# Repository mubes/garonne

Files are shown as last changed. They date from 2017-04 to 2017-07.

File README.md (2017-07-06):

```
                                       ++++++++++++++++++  
                                  +++++++++++++++++++++++++++++   
                              +++++++                      +++++++++  
                          +++++++                               +++++++++++++   
         ++++++++++++++++++++                                         ++++++++++   
    +++++++++++++++++++++                                                     +++  
   +++++                                                                       +++  
  +++         ######### ######### ########  #########  #########   +++++++      ++  
  +++  +++++ ####  #### ######## ####  #### ##### #### #### ####  +++  ++++    +++  
  +++   ++++ ###     ## ###      ###    ### ###    ### ###    ### ++++++++   +++  
   ++++ ++++ ########## ###      ########## ###    ### ###    ### ++++    +++++  
    +++++++   ###### ## ###       ########  ###     ## ##     ###  ++++++++++  
```

Introduction
============
The Garonne project is a simple infrastructure for autonomous and ADAS model vehicles. It
has been run on numerous embedded and application platforms. The system consists of 
a Low Level Board (LLB) which is a real time embedded plaform (optionally multi-core)
and a High Level Board (HLB) which performs the 'reasoning' behind the actions the 
system takes.  Many different platforms have been used for the HLB and the LLB including
Tegra TK1 and full blown PCs. 

Its designed to be cheap to build, modify and crash....but to be a reasonably powerful
and extensible platform at the same time.

In the current implementation, for ease of access, the High Level Board is minimally a 
Raspberry Pi and the Low Level Board is a NXP LPCXpresso LPC4367 204MHz CORTEX-M4 + 2x
CORTEX M0 which provides a significant amount of real time computing power. The HLB
runs Linux, programmed in Python, and the LLB is based on FreeRTOS and is programmed
in C. The Commander (that animates the system and provides objectives to be reached) can
run on pretty much anything, but the simple code provided will work perfectly well on a
second RaspberryPi....you can even use Force Feedback wheels etc. for 'driving' the vehicle remotely.

The project was orignally created by Technolution BV. It was first demonstrated at the 
ITS World Congress in Bordeaux in 2016 (Hence, the codename 'Garonne', the river that 
Bordeaux lies on) based on bespoke hardware. It has been ported to COTS hardware by
Technolution and is now released for open use.

Getting Started
===============
Generally speaking, a Garonne system will consist of at least one vehicle, a control platform
(consisting of a Low Level Board (LLB) and a High Level Board (HLB) and a command platform,
which is generally remote. All of this runs on a physical vehicle which ends up
looking something like this;

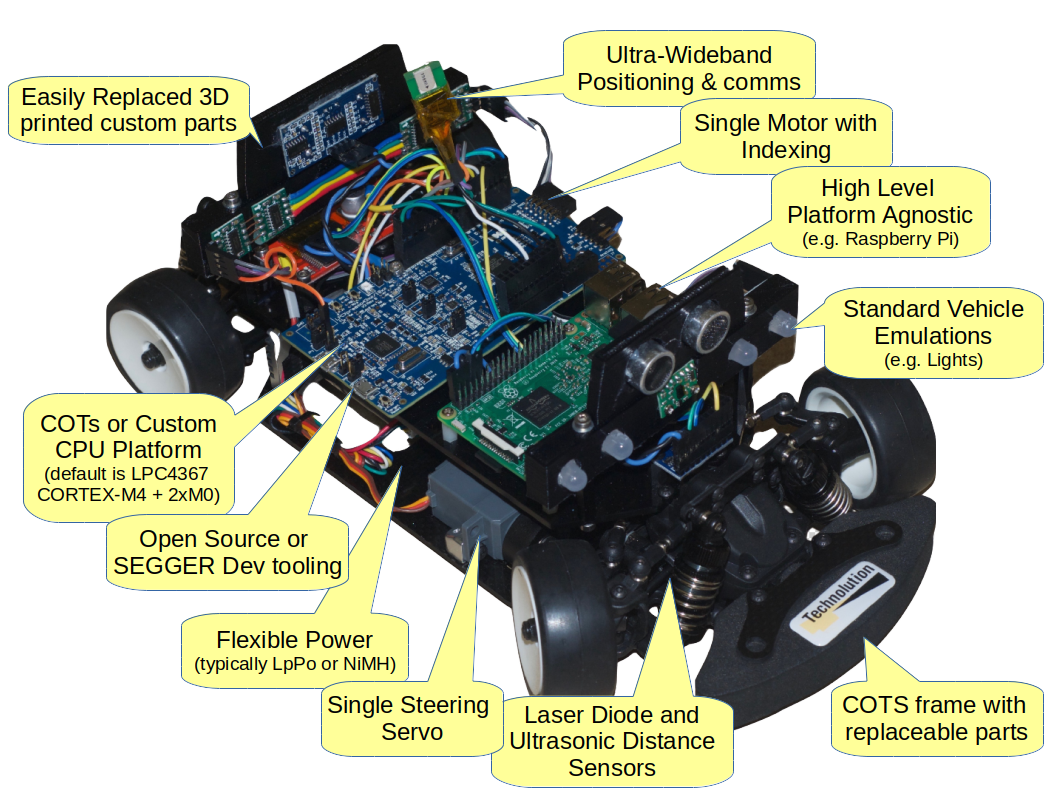
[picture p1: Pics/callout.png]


...so, let's get started;

Physical Vehicle
----------------
Generally speaking, you can use most remote controlled cars for the physical vehicle, the requirements
are not very onerous. 

The shopping list looks like the following (Full list of compnents and quantities is at the foot of this note);

* ***M.Rage chassis, assembled***.  [Hobbyking](https://hobbyking.com/en_us/bsr-racing-m-rage-1-10-4wd-m-chassis-un-assembled-kit.html). The assembled bit is an exercise for the reader.

* ***Steering Servo***...just a bog standard analogue servo will be fine. Something like [this](https://hobbyking.com/en_us/turnigytm-tgy-9025mg-mg-servo-1-8kg-0-09sec-11g.html).

* ***Pololu motor***, mounted in chassis, with drive pinion. We use the 4.4:1 variant which is expensive, but comes with itw own encoder and they're available from distributors around the world. [Pololu item number 2270] (https://www.pololu.com/product/2270).

* ***Drive Pinion***. The most specific bit of the whole setup. These are 31 tooth 48P pinions with 5mm bore. We get ours from neil at rwracing.co.uk. Take a guess at his email address.

* ***Power Switch***. You can use anything for this really, but the plastics have a 13x19.5 hole cut to take a snap-in switch. The ones we have are marked KCD1-104 and work fine. Available for cheap from the usual outlets.

* ***Mounting plastic for the electronics***. No way out of this one, you've got to make them, or talk very nicely to me to see if we've got any spare, we often have, but shipping outside of local territory tends to end up more expensive than making new ones.  The drawings to make them from are in the git repository, and [Elecrow] (https://www.elecrow.com/) will make you more than you'll ever need in 3mm acrylic for very cheap.

* ***LPC4367 LPCXpresso board***. These are available from [Farnell] (http://uk.farnell.com/nxp/om13088/dev-board-32bit-dual-core-mcu/dp/2519578) and elsewhere.  Again, not cheap, but you're getting a CORTEX-M4 and two CORTEX-M0 CPUs here, complete with development environment and debugger.

* ***MPU9250 9D sensor board***. Search for '9DOF MPU9250' or similar on eBay. It's just a chip on a board so it's difficult for them to screw it up too badly. Make sure you end up with a 9250 board and not a 65 series board though....they're largely identical but the one with MPU65 written on the top doesn't have the magnetometer built in.

* ***Raspberry Pi 3***...'nuff said. The plastics also support the little mini ones, and the PiW has wifi on now too. Which one you choose is dependent on how much processing you want to do on the vehicle. We've used all sorts for this job from a Pi to a TEGRA K1 and a Parallella. You can connect to the LLB via TTL-serial or USB, so there's flexibility here.

* ***VHN2SP30 motor driver***. Again, this is an eBay job.  You only need the single one, not the dual that is set up as an Arduino shield.

* ***5V power supply***. There are 1001 of these. We use the little MP1584 modules set to 5V with a dab of nail varnish on the pot afterwards. Use whatever you prefer but *beware* there are many stories of fake modules coming out of China. They usually work fine but I wouldn't trust them anywhere near their stated current limits!

In addition to this lot you will need some male to female and female to female 10cm and 20cm Dupont 
jumpers, and some nylon m3 standoff pillars. In the Wiring directory you will find a set of wiring digrams for Power;

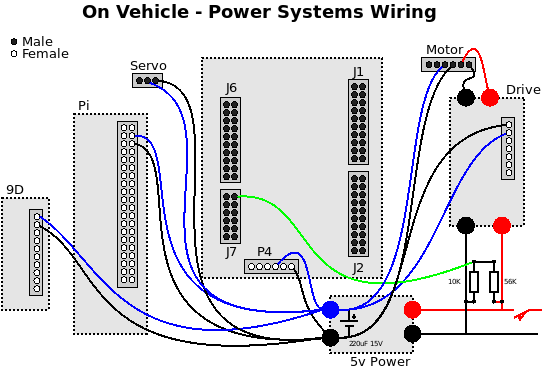
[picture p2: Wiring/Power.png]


... and for signalling;

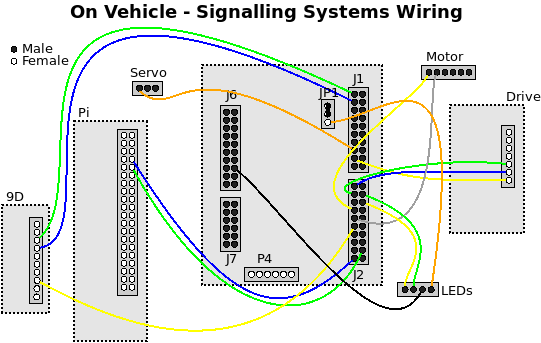
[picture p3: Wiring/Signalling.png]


Higher resolution versions of these diagrams can be found in the `Wiring` directory in PDF format.

Low Level Board
---------------
Bringing up the Low Level Board (LLB) requires the use of the GNU ARM gcc compiler suite. You can download that directly from [ARM] (https://developer.arm.com/open-source/gnu-toolchain/gnu-rm) and then use something like GNU ARM Eclipse to fold it into an IDE (http://gnuarmeclipse.github.io/) or, the easier option, is to head over to NXP and download either LPCXpresso or MPUXpresso from their site. MCUXpresso is the more recent suite, and is arguably more powerful, but it's a new product and at the time of writing we found LPCXpresso 8.2.2 to be more solid than MCUXpresso 10.0.0....but the letter is likely to be updated frequently, so YMMV.  Having said that, as we've brought up the M0 cores, we've not found either of these suites to be great, so we've installed the Segger JLink firmware (available for download from the [Segger Site](https://www.segger.com/jlink-lpcxpresso-ob.html) ) and used it with the [GNU Arm Eclipse](http://gnuarmeclipse.github.io/) setup. This makes for quite an impressively capable setup.

The code for the LLB is well commented and will build directly from the Makefile with a `make` command...or import it as a makefile project into one of the aforementioned environments.  It will flash directly onto the LLB using the built in debugger. You've got to go a _long_ way out of your way to brick this setup...indeed, I doubt you could do it without deliberately setting out to do so.

Structure of the LLB Code
-------------------------

The LLB code is reasonably well structured, and there are lots of optional components that can be included via conditionals in the makefile (e.g. for networking, SD cards and CAN interfaces).  The primary components to be interested in are;

* `config.h` : The main configuation file, which pulls in a susbsidiary configuration file `config-lpc4367.h` or `config-lpc4370.h` which are the only two we have released. In each of these files you will find things like pin allocations for the various components and the configuration of I/O flows (e.g. which UART is used for the UI and which is used for HLB communication, for example). In general make changes in these files rather than the program files themselves where possible.

The code for the various CPUs lives in subdirectories. For now we only concern ourselves with the m4 code, which we split into several groups;

----
**Program Flow Control**

* `main.c`: Sets up the system, calls essential configuration routines, and then gets out of the way having gotten everthing going.  The main thread of execution is maintained in...

* `mainloop.c`: Runs two threads. One for the i2c tasks, and one for the primary tasks.  These are seperated to avoid timing dependencies between the two. After initialisation the two threads in `mainloop:_mainThread` and `mainloop:i2cThread` represent the backbone of execution for the system.

* `ui.c`: The management and reporting UI. Not generally used in active operation, but very useful for debug and proving.

----
**Offboard Communications**

* `serport.c`: Abstracted interface to all of the serial ports, both 'real' TTL ones and 'virtual' USB ones.

* `lmsMsg.c`, `lms_rx.c` & `lms.c`: The interface to/from the HLB. All messages are encoded and decoded here before being dispatched to the right places.

* `uartHandler.c`: Looks after the 'real' UARTs.

----
**I/O**
 
* `gio.c`: The generic I/O module. Looks after the flashing lights, ADC and other low level stuff that is not worthy of its own module.

* `leds.c`: Code for driving LED strings (for indicators and headlights etc.).

----
**Device Drivers and Real World Interfaces**

* `rotenc.c`: Provides a clever little routine to maintain the rotary encoder count from the motor.

* `dist.c`: Distance measuring via whatever transducers are in use.

* `vldist.c`: Distance module when using the ST VL transducer.

* `motor.c`: Motor (actuator) driving for both the direct drive motor and the Servo.

* `can.c`: Is a prototypical CAN interface. It was used for hardware proving and is not active in current builts.

* `audio.c` : Is a simple DMA based audio handler. Not wired in one the current board, but can trivially be added. The samples it plays out are stored in `speedy.c`.

* `sdif.c`: Is the iterface to the SD Card that can be used for recording logging data etc. This was used in hardware proving and is not active in current builds.

* `nined.c`: Simple i2c interface to the 9D sensor. 

* `i2chandler.c`: Generic i2c handler.

* `usb/`: Files relating to the USB interface. Most of the interface is implemented by ROMmed routines, but this code provides the interface to those.

* `enet/`: Files relating to the Ethernet interface.  This is not active/needed at the moment (these files were used for hardware proving) but it's trivial to add by just provisioning a connector onto J6 of the LLB....previous versions of Garonne have used Ethernet for the interface between the LLB and the HLB

----
**System Management**

* `fault_handler.c`: Provides support for debugging the bane of every ARM programmers life, HardFaults.

* `config.c`: Configuation support and Non-volatile storage. Asserts and debug printing are also handled in here.

* `stats.c`: Simple stats management package for FreeRTOS....it's really useful to know just how busy the CPU is!
                                                               
* `llb_init.c` & `startup_lpc43xx.c`: Deal with the booting of the system.

There is code that runs on the M0 board for interfacing to the Ultrawideband radio and a Quaterion structure for the 9D sensor. I'm afraid we can't make the source code for these files openly availble but you're free to use the code with the Garonne platform (See the licence in the `bindist` directory, where the binary blob also lives).  If you _do_ need access to the source for this module then drop us a note and we will sort something out...but we've got to eat too!

High Level Board
----------------
The high level board is reponsible for the 'reasoning' that the on-board systems have to perform. It's also responsible for the interface to the outside world (over WiFi, in the implementation that is released). It's based on a RaspberryPi and a Pi3 or ZeroW both offer the WiFi on board.

The image on the board is based on Rasbian (downloadable from the Pi Foundation), then install Python3, the PySerial and evdev extensions, and you're ready to run the `vehicleserver` which is in the `python` directory of the distribution. You can edit the file `/etc/rc.local` and add the following lines to get the system to auto-start;

```
/sbin/iwconfig wlan0 power off
/home/icarus/runvs >> /home/icarus/vehicleserver.log 2>&1 &
```

If you _do_ decide to to start `vehicleserver` from the command line then the `-v` option will provide you with some information as to what it is doing.  In general, the vehicleserver won't do anything except the status quo until it receives a command from the outside world, which brings us to the highest level of the system;

Commander
---------

The commander is the part of the system that tells the vehicle(s) what to do. In the released implementation you will find a `wheelclient` in the `python` directory of the distribution. This allows a number of different controllers to be used to control the vehicle directly. Currently supported controllers are;

* Logitech G29 Driving Force Racing Wheel (uses the force feedback - currently the best choice)
* Generic Steering Wheel Controller
* PLAYSTATION(R)3 Controller over Bluetooth
* Goodbetterbest Ltd Gioteck VX2 Wired Controller
* Microsoft X-Box 360 pad

When multiple controllers are connected to the Commander the selection amongst them will be performed in the order listed above.  Adding new controllers is trivial via the code in `wheelclient`.

`wheelclient` will run on any Linux-style platform. For convinience it is often run on a second RasberryPi...indeed, if you're using a Bluetooth controller, it can even be run on the HLB.

`wheelclient` needs to be told where to 'find' the HLB on the network. A typical invocation of `wheelclient` would therefore be;

```
wheelclient -s icarus32n4.local
```

Parts List
----------

| Component | Per Vehicle |
| ---|:---:|
| Frame		 | 1 |
| Plastic Motor Mount	 | 1 |
| Polulu 2270 motor	 | 1 |
| Servo Motor | 1 |
| 31 tooth 48P pinion with 5mm bore	 | 1 |
| Acrylic Baseplate | 1 |
| 10mm M2.5 Nylon Spacer 	 | 4 | 
| 10mm M3 Nylon Spacer	 | 9 |
| m3 nut	 | 9 |
| 30mm Nylon Hex Standoff	 | 4 |
| 6mm M3 Hex Head bolt	 | 13|
| M3 Washer | 4 |
| 8mm M2.5 Cross Head Screw	 | 4 |
| 10x1 Dupont Housing | 1 |
| 10x2 Dupont Housing | 3 |
| 7x1 Dupont Housing | 1 |
| 6x2 Dupont Housing | 1 |
| 6x1 Dupont Housing | 1 |
| 20x2 Dupont Housing | 1 |
| 10cm 40 way Male to Female Dupont Jumper | 1 |
| 20cm 40 way Male to Female Dupont Jumper	 | 1 |
| 15cm 40 way Male to Female Dupont Jumper	 | 1 |
| Hookup wire for Battery (Black & Red)		 | 1 |
| Hookup wire for 5V Distribution (Black & Blue) | 1 |
| 56K 1/4 Watt Resistor	 | 1 |
| 10K 1/4 Watt Resistor	 | 1 |
| MPU9250 9D Sensor Board	 | 1 |
| Raspberry Pi 3 or PiW	 | 1 |
| 8GB uSD Card | 1 |
| Ultrasonic Transducer	 | 2 |
| LPC4367 LPCXpresso board	 | 1 | 
| VHN2SP30 Motor Driver Board	 | 1 |
| MP1584 PSU (Adjust to 5V)	 | 1 |
| KCD1-104 Power Switch | 1 |
| DWM1000 Module | 1 |

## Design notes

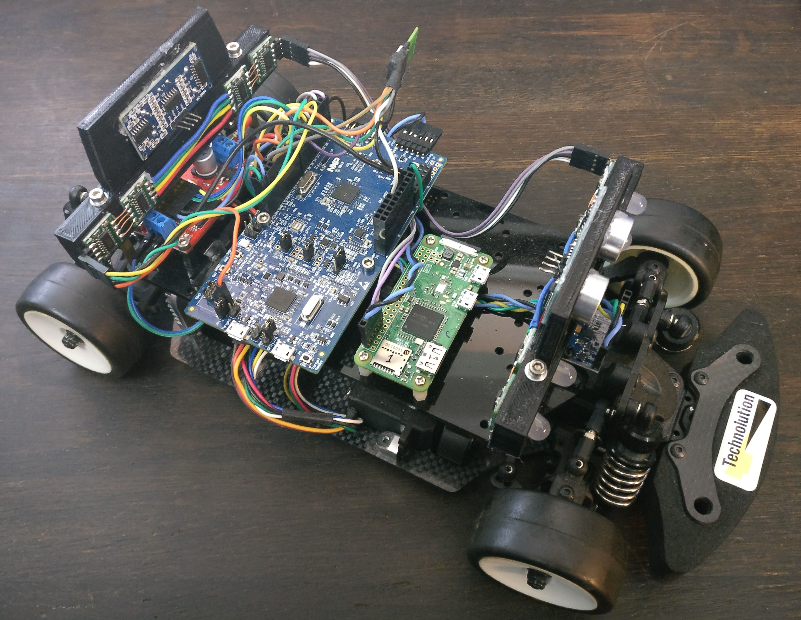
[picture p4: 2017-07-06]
Pics/Vehicle.jpg

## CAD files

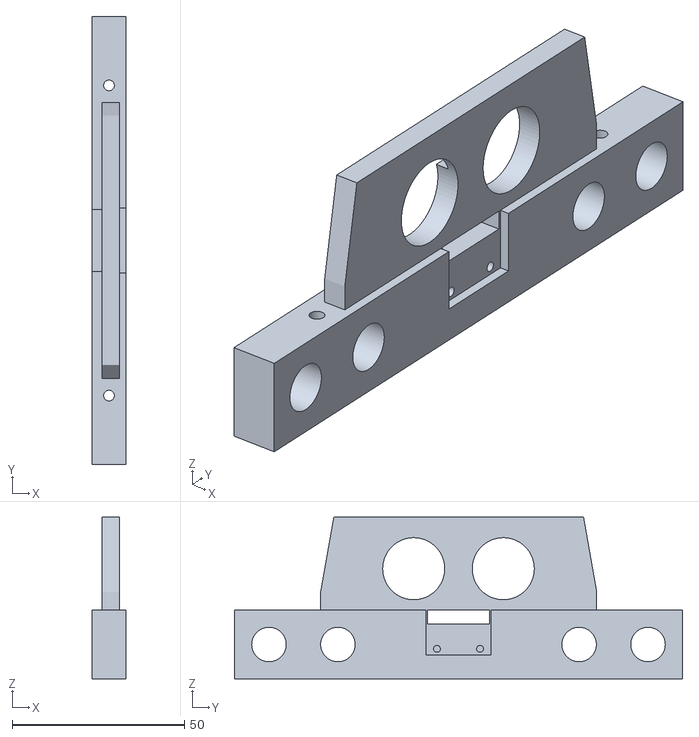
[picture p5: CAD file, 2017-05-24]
prints/bakcrossbar.stl
10.0 x 130.0 x 47.0

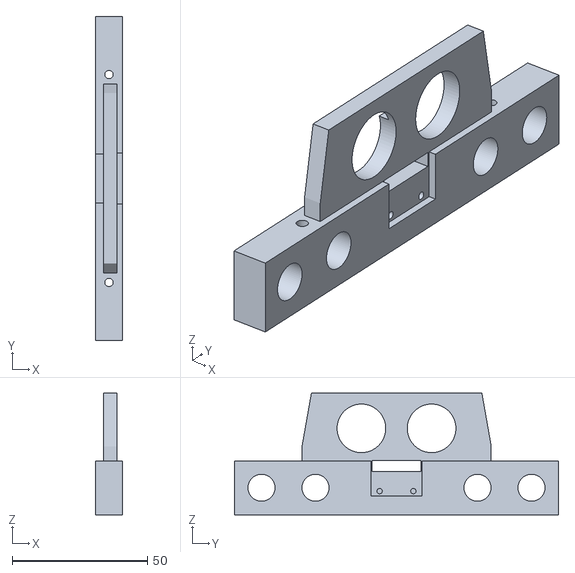
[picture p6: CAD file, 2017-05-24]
prints/frontcrossbar.stl
10.0 x 120.0 x 45.0

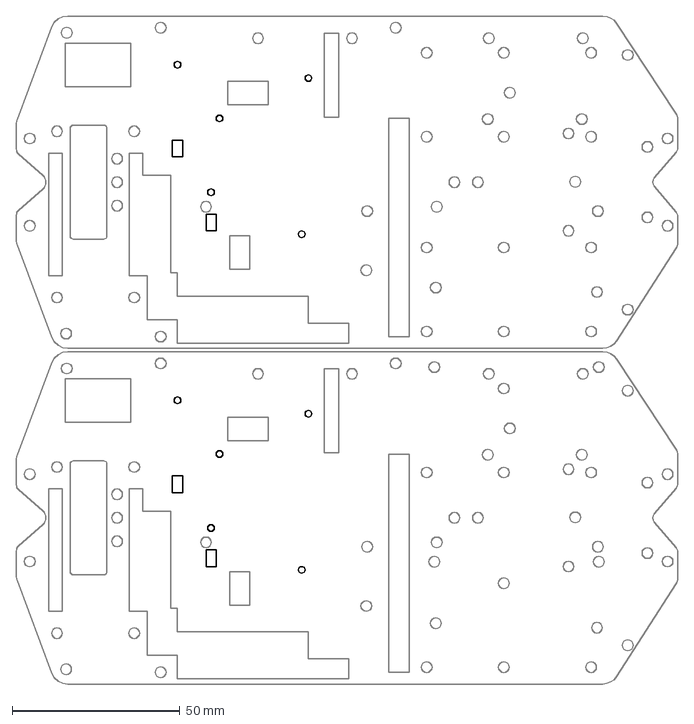
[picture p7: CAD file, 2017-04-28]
prints/top-v4.dxf
197.0 x 199.0 mm

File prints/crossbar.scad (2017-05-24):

$fn=64;
rlength=100;
length=120;
backlength=130;
width=10;
height=20;

frontcutdepth=2;
frontwidth=19;
frontDepth=13;
hcentres=12.5;
hdep=7.25;

topcutdepth=4;
topcutwidth=18;

postDia=6.8;
screwDia=3.1;
postDist=77;

backpostDist=90;
rpostDist=89.5;
fixrecess=9;

radioWidth=7;
radioDepth=12;
radioLength=14;
radioHold=radioLength+12;
radioHole=4;

module front()
{
difference()
{
    // Top block
    union()
    {
        cube([width,length,height]); 
        translate([3,25,height-0.01]) cube([width-5,length-50,35]);
    }

    // Slopes for upper panel
    translate([0,17,height+6]) rotate([-10,0,0]) cube([width,8,70]);
    translate([0,length-25.01,height+6]) rotate([10,0,0]) cube([width,8,70]);

    
    // LED holes
        translate([-3,30,10]) rotate([0,90,0]) cylinder(r=5,h=15);
        translate([-1,20,10]) rotate([0,90,0]) cylinder(r=1,h=8);
        translate([-3,10,10]) rotate([0,90,0]) cylinder(r=5,h=15);
        translate([-1,length/2,10]) rotate([0,90,0]) cylinder(r=1,h=8);    
        translate([-3,length-30,10]) rotate([0,90,0]) cylinder(r=5,h=15);
        translate([-1,length-20,10]) rotate([0,90,0]) cylinder(r=1,h=8);
        translate([-3,length-10,10]) rotate([0,90,0]) cylinder(r=5,h=15);
    
    
    
    // Uptrasonic holes
   translate([0,length/2-13,height+12]) rotate([0,90,0]) cylinder(r=9,h=12);
   translate([0,length/2+13,height+12]) rotate([0,90,0]) cylinder(r=9,h=12);
    translate([1,length/2-8,height+15]) cube([5,16,8]);    
   
   // Camera
   translate([0,length/2,height+42]) rotate([0,90,0]) cylinder(r=15,h=12);    
    translate([0,length/2+13.5,height+27]) rotate([0,90,0]) cylinder(r=2,h=12);
    translate([0,length/2-13.5,height+27]) rotate([0,90,0]) cylinder(r=2,h=12);
    
    // Front cutout for laser
    translate([width-frontcutdepth+0.01,(length-frontwidth)/2,height-frontDepth]) cube([frontcutdepth,frontwidth,frontDepth+1.05]);
   
   // Holes for moutning VL laser 
    translate([width,(length-hcentres)/2,height-topcutdepth-hdep]) rotate([0,-90,0]) cylinder(r=1,h=8);
    translate([width,(length+hcentres)/2,height-topcutdepth-hdep]) rotate([0,-90,0]) cylinder(r=1,h=8);
 
        // Top recess for Dupont connector
  translate([-0.01,(length-topcutwidth)/2,height-topcutdepth]) cube([width,topcutwidth,topcutdepth+0.05]);
    
    
    // Mounting screws
    translate([width/2,(length-postDist)/2,-0.01])  
    {
        cylinder(r=postDia/2,h=fixrecess);
        cylinder(r=screwDia/2,h=height+0.05);
    }
    
    translate([width/2,length-(length-postDist)/2,-0.01])  
    {
        cylinder(r=postDia/2,h=fixrecess);
        cylinder(r=screwDia/2,h=height+0.05);
    }
    
    // Remove top when there's no camera mount needed
    translate([0,0,height+25]) cube([10,100,height+25]);
    
}    
}

module back()

{
difference()
{
    // Top block
    union()
    {
        cube([width,backlength,height]); 
        translate([3,25,height-0.01]) cube([width-5,backlength-50,27]);
    }
    
        // Slopes for upper panel
    translate([0,17,height+6]) rotate([-10,0,0]) cube([width,8,70]);
    translate([0,backlength-25.01,height+6]) rotate([10,0,0]) cube([width,8,70]);

    // Uptrasonic holes
   translate([0,backlength/2-13,height+12]) rotate([0,90,0]) cylinder(r=9,h=12);
   translate([0,backlength/2+13,height+12]) rotate([0,90,0]) cylinder(r=9,h=12);
    translate([1,backlength/2-8,height+15]) cube([5,16,8]);  

    
    // LED holes
        translate([-3,30,10]) rotate([0,90,0]) cylinder(r=5,h=15);
        translate([-1,20,10]) rotate([0,90,0]) cylinder(r=1,h=8);
        translate([-3,10,10]) rotate([0,90,0]) cylinder(r=5,h=15);
        translate([-1,backlength/2,10]) rotate([0,90,0]) cylinder(r=1,h=8);    
        translate([-3,backlength-30,10]) rotate([0,90,0]) cylinder(r=5,h=15);
        translate([-1,backlength-20,10]) rotate([0,90,0]) cylinder(r=1,h=8);
        translate([-3,backlength-10,10]) rotate([0,90,0]) cylinder(r=5,h=15);
       
    // Front cutout for laser
    translate([width-frontcutdepth+0.01,(backlength-frontwidth)/2,height-frontDepth]) cube([frontcutdepth,frontwidth,frontDepth+1.05]);
   
   // Holes for moutning VL laser 
    translate([width,(backlength-hcentres)/2,height-topcutdepth-hdep]) rotate([0,-90,0]) cylinder(r=1,h=8);
    translate([width,(backlength+hcentres)/2,height-topcutdepth-hdep]) rotate([0,-90,0]) cylinder(r=1,h=8);
 
        // Top recess for Dupont connector
  translate([-0.01,(backlength-topcutwidth)/2,height-topcutdepth]) cube([width,topcutwidth,topcutdepth+0.05]);
    
    
    // Mounting screws
    translate([width/2,(backlength-backpostDist)/2,-0.01])  
    {
        cylinder(r=postDia/2,h=fixrecess);
        cylinder(r=screwDia/2,h=height+0.05);
    }
    
    translate([width/2,backlength-(backlength-backpostDist)/2,-0.01])  
    {
        cylinder(r=postDia/2,h=fixrecess);
        cylinder(r=screwDia/2,h=height+0.05);
    }
    
}    
}


//rotate([0,0,180]) translate([0,-50-(length/2),0]) 
back();
//translate([2,0,0]) back();

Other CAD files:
prints/top-v4.dwg

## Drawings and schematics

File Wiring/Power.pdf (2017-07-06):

## On Vehicle - Power Systems Wiring

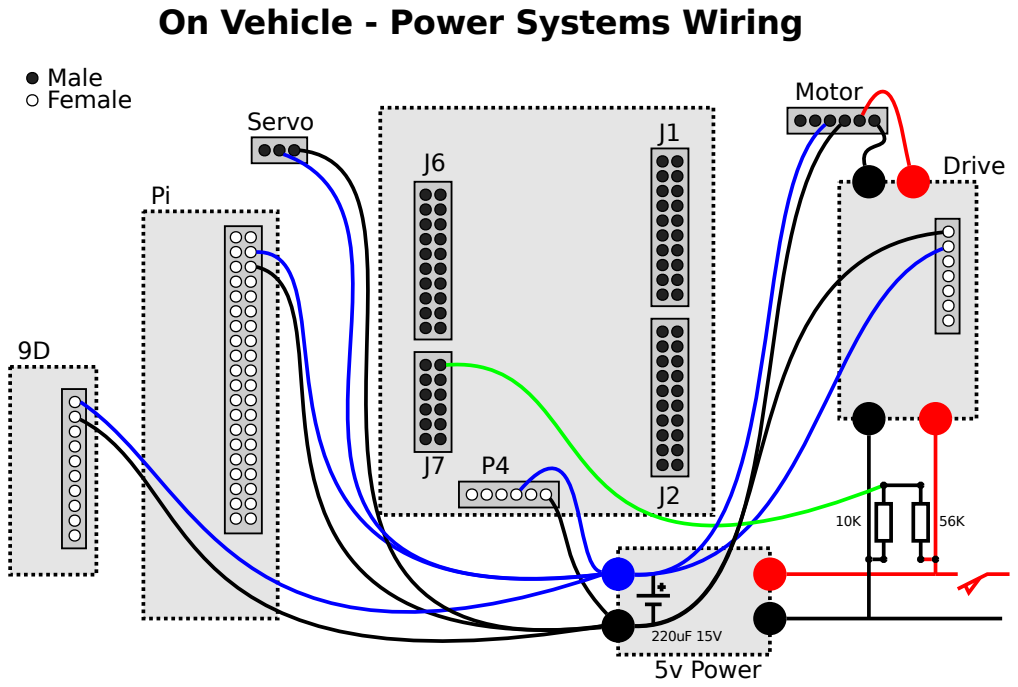
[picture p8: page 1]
Motor; Servo; Drive; Male Female; 5v Power

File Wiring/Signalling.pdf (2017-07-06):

## On Vehicle - Signalling Systems Wiring

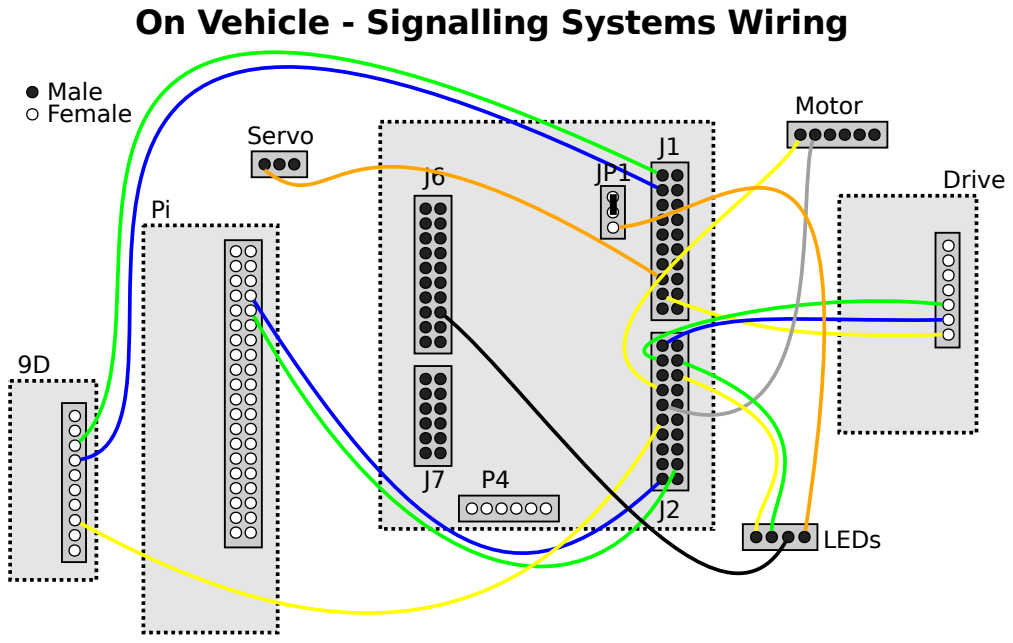
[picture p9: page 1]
Motor; Servo; Drive; Male Female; LEDs

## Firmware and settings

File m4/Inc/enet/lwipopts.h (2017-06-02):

#ifndef __LWIPOPTS_H_
#define __LWIPOPTS_H_

/* RTOS build */
#define NO_SYS                          0

/* Use LWIP timers */
#define NO_SYS_NO_TIMERS                0

/* Need for memory protection */
#define SYS_LIGHTWEIGHT_PROT            1

/* 32-bit alignment */
#define MEM_ALIGNMENT                   4

/* pbuf buffers in pool. In zero-copy mode, these buffers are
   located in peripheral RAM. In copied mode, they are located in
   internal IRAM */
#define PBUF_POOL_SIZE                  5

/* No padding needed */
#define ETH_PAD_SIZE                    0

#define IP_SOF_BROADCAST                1
#define IP_SOF_BROADCAST_RECV           1

/* The ethernet FCS is performed in hardware. The IP, TCP, and UDP
   CRCs still need to be done in hardware. */
#define CHECKSUM_GEN_IP                 1
#define CHECKSUM_GEN_UDP                1
#define CHECKSUM_GEN_TCP                1
#define CHECKSUM_CHECK_IP               1
#define CHECKSUM_CHECK_UDP              1
#define CHECKSUM_CHECK_TCP              1
#define LWIP_CHECKSUM_ON_COPY           1

/* Use LWIP version of htonx() to allow generic functionality across
   all platforms. If you are using the Cortex Mx devices, you might
   be able to use the Cortex __rev instruction instead. */
#define LWIP_PLATFORM_BYTESWAP          0
#define MEM_SIZE                        (12 * 1024)

/* Raw interface not needed */
#define LWIP_RAW                        0

/* DHCP is ok, UDP is required with DHCP */
#define LWIP_DHCP                       1
#define LWIP_UDP                        1

/* Hostname can be used */
#define LWIP_NETIF_HOSTNAME             1

#define LWIP_BROADCAST_PING             1

/* MSS should match the hardware packet size */
#define TCP_MSS                         1460
#define TCP_SND_BUF                     (2 * TCP_MSS)

#define LWIP_SOCKET                     0
#define LWIP_NETCONN                    1
#define MEMP_NUM_SYS_TIMEOUT            300

#define LWIP_STATS                      0
#define LINK_STATS                      0
#define LWIP_STATS_DISPLAY              0

#ifdef DEBUG
    #define LWIP_DEBUG                      1
#endif

#define LWIP_DEBUG 1

/* There are more *_DEBUG options that can be selected.
   See opts.h. Make sure that LWIP_DEBUG is defined when
   building the code to use debug. */
#define TCP_DEBUG                       LWIP_DBG_OFF
#define ETHARP_DEBUG                    LWIP_DBG_OFF
#define PBUF_DEBUG                      LWIP_DBG_OFF
#define IP_DEBUG                        LWIP_DBG_OFF
#define TCPIP_DEBUG                     LWIP_DBG_OFF
#define DHCP_DEBUG                      LWIP_DBG_OFF
#define UDP_DEBUG                       LWIP_DBG_OFF

/* This define is custom for the LPC EMAC driver. Enabled it to
   get debug messages for the driver. */
#define EMAC_DEBUG                    LWIP_DBG_OFF

#define DEFAULT_THREAD_PRIO             (tskIDLE_PRIORITY + 1)
#define DEFAULT_THREAD_STACKSIZE        (150)
#define DEFAULT_ACCEPTMBOX_SIZE         4
#define DEFAULT_TCP_RECVMBOX_SIZE       4
#define DEFAULT_UDP_RECVMBOX_SIZE       4

#define IRQ_PRIO_ETHERNET               config_ETHERNET_INTERRUPT_PRIORITY

/* TCPIP thread must run at higher priority than MAC threads! */
#define TCPIP_THREAD_PRIO               (DEFAULT_THREAD_PRIO + 2)

#define TCPIP_THREAD_NAME               "TCP Thr"
#define TCPIP_THREAD_STACKSIZE          (224)

#define TCPIP_MBOX_SIZE                 4

#define MEM_LIBC_MALLOC                 0
#define MEMP_MEM_MALLOC                 0

/* Required for malloc/free */
#include <stdlib.h>
#include <stdint.h>
#include <string.h>
#include "lpc_types.h"
#include "FreeRTOS.h"

#endif /* __LWIPOPTS_H_ */

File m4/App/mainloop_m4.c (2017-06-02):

/*
*                                       ++++++++++++++++++
*                                  +++++++++++++++++++++++++++++
*                              +++++++                      +++++++++
*                          +++++++                               +++++++++++++
*         ++++++++++++++++++++                                         ++++++++++
*    +++++++++++++++++++++                                                     +++
*   +++++                                                                       +++
*  +++         ######### ######### ########  #########  #########   +++++++      ++
*  +++  +++++ ####  #### ######## ####  #### ##### #### #### ####  +++  ++++    +++
*  +++   ++++ ###     ## ###      ###    ### ###    ### ###    ### ++++++++   +++
*   ++++ ++++ ########## ###      ########## ###    ### ###    ### ++++    +++++
*    +++++++   ###### ## ###       ########  ###     ## ##     ###  ++++++++++
*
* Copyright 2017 Technolution BV  opensource@technolution.eu
*
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
* MAINLOOP module
* ===============
*
* This module is the main control heartbeat for the system.
*
*/


#include "../Inc/ipcMsg.h"
#include "gio.h"
#include "uartHandler.h"
#include "ui.h"
#include "stats.h"
#include "iap.h"
#include "i2chandler.h"
#include "ui.h"
#include "serport.h"
#include "dist.h"
#include "vldist.h"
#include "motor.h"
#include "rotenc.h"
#include "lms.h"
#include "mainloop.h"
#include "leds.h"
#include "sdif.h"
#include "enet.h"
#include "audio.h"
#include "can.h"
#include "generics.h"
#include "ipcHandler.h"
#include "serdes.h"
#include "ipcMsg.h"

/* Intervals at which data are asynchronously sent to HLB */
#define BATTERY_STATUS_INTERVAL (MILLIS_TO_TICKS(1000))        /* How often to check battery status */
#define LEDCHECK_INTERVAL       (MILLIS_TO_TICKS(100))         /* How often to check LED status */
#define REVS_ENC_TX_INTERVAL    (MILLIS_TO_TICKS(100))         /* How often to send revs (encoder) status */
#define VEHICLE_STATUS_INTERVAL (MILLIS_TO_TICKS(50))          /* How often to send vehicle status */
#define VL_INTERVAL             (MILLIS_TO_TICKS(100))         /* How often to send laser distance data */
#define PSNQ_TX_INTERNVAL       (MILLIS_TO_TICKS(50))          /* How often to send position and quaternion data */
#define NINEDENC_INTERVAL       (MILLIS_TO_TICKS(105))         /* How often to send nined data */
#define M0WATCHDOG_INTERVAL     (MILLIS_TO_TICKS(2000))        /* Maximum time since we last heard from the watchdog */
#define M0WATCHDOG_CHKINTERVAL  (MILLIS_TO_TICKS(4000))        /* How often the M0 watchdog is checked */

struct MLStruct
{
    xTaskHandle task;
    xTaskHandle i2ctask;
} _m;
// ============================================================================================
static portTASK_FUNCTION( _i2cThread, pvParameters )

/* A task dedicated to i2c handler activities */

{
    uint32_t evSet;
    uint32_t nowTicks;
    uint32_t lastvl = 0;     /* Last time VL sensor was read */

    BOOL haveVLSensor = FALSE;

    /* It's important that the VLInit is done before LEDInit 'cos the I2C IDs clash...so VLInit moves them out of the way */
#ifdef VL_DISTANCE
    haveVLSensor = VLDISTInit( TICKS_TO_MILLIS( VL_INTERVAL ) );
#endif

    LEDInit();
    vTaskDelay( GYRO_WAKEUP_TIME );

    while ( 1 )
    {
        xTaskNotifyWait( 0, 0xFFFFFFFF, &evSet, MILLIS_TO_TICKS( 10 ) );
        nowTicks = xTaskGetTickCount();

#ifdef VL_DISTANCE

        if ( ( haveVLSensor ) && ( nowTicks - lastvl > VL_INTERVAL ) )
        {
            VLDISTCheckOutput();
            lastvl = nowTicks;
        }

#endif
    }
}
// ============================================================================================
EVENT_CB( _ipcEv )

/* routine that is called when an IPC transaction is triggered */

{
    BaseType_t xTaskWoken = MLUpdateAvailableFromISR( ( j == IPC_APP ) ? EVENT_M0APP : EVENT_M0SUB );
    portEND_SWITCHING_ISR( xTaskWoken );
}
// ============================================================================================
static portTASK_FUNCTION( _mainThread, pvParameters )

/* The main startup block, run as a task to ensure the scheduler is active */

{
    uint32_t lastRevsEnc = 0;         /* Last time revs were sent */
    uint32_t lastStatusEnc = 0;       /* Last time vehicle status was sent */
    uint32_t lastBatteryEnc = 0;      /* Last time battery status was sent */
    uint32_t lastPsnQ = 0;            /* Last time position and quaternion was sent */
    uint32_t last9DEnc = 0;           /* Last time 9D was sent */
    uint32_t lastM0WatchdogCheck;     /* Last time M0 was checked */
    uint32_t nowTicks;                /* Current tick count */

    uint32_t evSet;                   /* Events that have been set */

    GIOSetup(); /* Its best to have the generic IO setup as the scheduler starts */
    statsInit(); /* Initialize statistics package */

    serportInit();
    LmsInit(); /* Initialize the messaging system in case we need it */
    motorInit();
#ifndef VL_DISTANCE
    DISTInit();
#endif
    RotencInit();
    UISetup();
    IPCMsgSetup();
    ipcInit( _ipcEv );

    /* Optional components */
#ifdef INCLUDE_ETHERNET
    enetInit();
#endif
#ifdef INCLUDE_SDMMC
    sdifSetup();
    sdifMount();
#endif
#ifdef INCLUDE_AUDIO
    audioInit();
#endif
#ifdef INCLUDE_CAN
    CANSetup();
#endif

    /* Don't even think about checking the M0 until it's had time to wake up */
    lastM0WatchdogCheck = xTaskGetTickCount();

    while ( 1 )
    {
        xTaskNotifyWait( 0, 0xFFFFFFFF, &evSet, MILLIS_TO_TICKS( 10 ) );
        nowTicks = xTaskGetTickCount();

        // ---------------------
        /* Most urgent to report on distance as a new reading can arrive any time */
        if ( evSet & ( 1 << SENSOR_TYPE_DISTANCE ) )
        {
            // distCheckOutput();
        }

        // ---------------------
        /* Check for anything happening over the serial ports */
        if ( evSet & ( 1 << LLB_IF_PORT ) )
        {
            LmsMsgReceive();
        }

        // ---------------------
        if ( evSet & ( 1 << TERMINAL_PORT ) )
        {
            CHECK( TRUE, UISeize( TRUE ) );
            UIProcessHandler( serportGetEvent( TERMINAL_PORT ) );
            CHECK( TRUE, UISeize( FALSE ) );
        }

        // ---------------------
        if ( evSet & ( 1 << EVENT_M0APP ) )
        {
            serdesReceive( IPC_APP );
        }

        // ---------------------
        if ( evSet & ( 1 << EVENT_M0SUB ) )
        {
            serdesReceive( IPC_SUB );
        }

        // ---------------------
        if ( evSet & ( 1 << EVENT_PRINT_LEDS ) )
        {
            LEDDoPrint();
        }

#ifndef VL_DISTANCE

        if ( evSet & ( 1 << SENSOR_TYPE_US_RANGE ) )
        {
            DISTCheckOutput();
        }

#endif
        // ---------------------
        if ( evSet & ( 1 << EVENT_USERBUTTON ) )
        {
            LmsSendUserbutton( GIOUserButtonState() );
        }

        /* =============================================== */
        /* Now deal with all of the interval based reports */
        /* =============================================== */
        if ( nowTicks - lastBatteryEnc > BATTERY_STATUS_INTERVAL )
        {
            LmsSendBatteryStatus( IPCMsgGetpsanandatt()->temp, 0, 0, GIOBattery() );
            lastBatteryEnc = nowTicks;
        }

        // ---------------------
        if ( nowTicks - lastStatusEnc > VEHICLE_STATUS_INTERVAL )
        {
            LmsSendCarStatus( motorGeteStop( MOTOR_ESTOP_FORWARDS ),
                              motorGeteStop( MOTOR_ESTOP_BACKWARDS ), motorServoGet(),
                              motorGetSpeed() );
            lastStatusEnc = nowTicks;
        }

        // ---------------------
        if ( nowTicks - lastRevsEnc > REVS_ENC_TX_INTERVAL )
        {
            RotencCheckOutput();
            lastRevsEnc = nowTicks;
        }

        // ---------------------
        if ( nowTicks - last9DEnc > NINEDENC_INTERVAL )
        {
            struct MSG9d *m = IPCMsgGet9d();

            LmsSend9DData( m->acc, m->gyr, m->mag );
            last9DEnc = nowTicks;
        }

        // ---------------------
        if ( nowTicks - lastPsnQ > PSNQ_TX_INTERNVAL )
        {
            struct MSGpsnandatt *m = IPCMsgGetpsanandatt();
            LmsSendPosandQ( m->psn, m->q, m->tsPsn, m->tsQ );
            lastPsnQ = nowTicks;
        }

        // ---------------------
        if ( nowTicks - lastM0WatchdogCheck > M0WATCHDOG_CHKINTERVAL )
        {
            if ( nowTicks - IPCMsgLastM0Ping() > M0WATCHDOG_INTERVAL )
            {
                /* We haven't heard for the M0 for a while - reset it */
                Chip_RGU_TriggerReset( RGU_M0APP_RST );
                Chip_Clock_Enable( CLK_M4_M0APP );

                /* Keep in mind the M0 image must be aligned on a 4K boundary */
                Chip_CREG_SetM0AppMemMap( M0_APPBASE );
                Chip_RGU_ClearReset( RGU_M0APP_RST );
            }

            lastM0WatchdogCheck = nowTicks;
        }

        // ---------------------

    }
}
// ============================================================================================
// ============================================================================================
// ============================================================================================
// Externally available routines
// ============================================================================================
// ============================================================================================
// ============================================================================================
void MLDistCheckOutput( void )

{
    // FIXME
    LmsSendBatteryStatus( IPCMsgGetpsanandatt()->temp, 0, 0, GIOBattery() ); // temperature actually read from 9D sensor...
}
// ============================================================================================
void MLUpdateAvailable( uint32_t sensor )

{
    xTaskNotify( _m.task, ( 1 << sensor ), eSetBits );
}
// ============================================================================================
void MLi2cUpdateAvailable( uint32_t event )

{
    xTaskNotify( _m.i2ctask, ( 1 << event ), eSetBits );
}
// ============================================================================================
BOOL MLUpdateAvailableFromISR( uint32_t sensor )

{
    BaseType_t xTaskWoken = FALSE;
    xTaskNotifyFromISR( _m.task, ( 1 << sensor ), eSetBits, &xTaskWoken );
    return xTaskWoken;
}
// ============================================================================================
void MLInit( void )

{
    ConfigInit(); /* Get the configuration (or default) before doing anything else */

    i2cInit();

    xTaskCreate( _mainThread, "mainLP", 512, NULL,
                 ( tskIDLE_PRIORITY + 1UL ), &_m.task );

    /* A loop for the time-intensive i2c handler */
    xTaskCreate( _i2cThread, "i2cLoop", 396, NULL,
                 ( tskIDLE_PRIORITY + 1UL ), &_m.i2ctask );
}
// ============================================================================================
// ============================================================================================
// ============================================================================================

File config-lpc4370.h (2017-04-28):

// ============================================================================================
// ============================================================================================
// ============================================================================================
// Start of LPC4370 specific setup
// ============================================================================================
// ============================================================================================
// ============================================================================================

// ----- Clocks (llb_init.c)
// -------------------------
#define CLOCK0    PINDEF(0, 0,  (SCU_MODE_INACT | SCU_MODE_INBUFF_EN | SCU_MODE_ZIF_DIS | SCU_MODE_HIGHSPEEDSLEW_EN | SCU_MODE_FUNC0))
#define CLOCK1    PINDEF(0, 1,  (SCU_MODE_INACT | SCU_MODE_INBUFF_EN | SCU_MODE_ZIF_DIS | SCU_MODE_HIGHSPEEDSLEW_EN | SCU_MODE_FUNC0))
#define CLOCK2    PINDEF(0, 2,  (SCU_MODE_INACT | SCU_MODE_INBUFF_EN | SCU_MODE_ZIF_DIS | SCU_MODE_HIGHSPEEDSLEW_EN | SCU_MODE_FUNC0))
#define CLOCK3    PINDEF(0, 3,  (SCU_MODE_INACT | SCU_MODE_INBUFF_EN | SCU_MODE_ZIF_DIS | SCU_MODE_HIGHSPEEDSLEW_EN | SCU_MODE_FUNC0))

// ----- FLASH (llb_init.c)
// ------------------------
#define SPIFI_SCK    PINDEF(0x3, 3,  (SCU_PINIO_FAST | SCU_MODE_FUNC3))
#define SPIFI_SIO3   PINDEF(0x3, 4,  (SCU_PINIO_FAST | SCU_MODE_FUNC3))
#define SPIFI_SIO2   PINDEF(0x3, 5,  (SCU_PINIO_FAST | SCU_MODE_FUNC3))
#define SPIFI_MISO   PINDEF(0x3, 6,  (SCU_PINIO_FAST | SCU_MODE_FUNC3))
#define SPIFI_MOSI   PINDEF(0x3, 7,  (SCU_PINIO_FAST | SCU_MODE_FUNC3))
#define SPIFI_CS     PINDEF(0x3, 8,  (SCU_PINIO_FAST | SCU_MODE_FUNC3))

// ---- CAN Parameters (can.c)
// ---------------------------
#define CAN_BITRATE 	(500000)
#define CAN_IF			LPC_C_CAN0
#define CAN_INTERFACE 	(CCAN_MSG_IF1)
#define CAN_RD			PINDEF(0x3, 1, (SCU_MODE_FUNC2|SCU_MODE_INBUFF_EN))
#define CAN_TD			PINDEF(0x3, 2, (SCU_MODE_FUNC2))

// ----- Stats timer (stats.c & FreeRTOSConfig.h)
// ----------------------------------------------
#define STATS_TIMER LPC_TIMER3

// ----- I2C (i2chandler.c)
// ------------------------
#define I2C0_MODE 						I2C0_FAST_MODE_PLUS
#define I2C0_BITRATE                    (400000)
#define I2C0_INTPRIORITY                (7)

// ----- DIST setup (either dist.c or vldist.c)
// --------------------------------------------
#define MINDIST                         (150)                           /* Minimum distance at which vehicle will eStop */
#ifndef VL_DISTANCE
// ----- DIST setup (dist.c)
#ifdef AM1
#define DIST_TRIG_FRONT                 GPIOPINDEF(0x0E, 9, SCU_MODE_FUNC4, 7, 9)
#define DIST_CAP_FRONT                  GIMAPINDEF(0x05, 0, (SCU_MODE_FUNC5 | SCU_MODE_INBUFF_EN | SCU_MODE_PULLDOWN), (2 << 4))        /* MOTOR[2].PWM pin used. (timer 1 capture input 0, GIMA select T1_CAP0) */
#define DIST_CAP_TIMER_INPUT_FRONT      (0)
#define DIST_TRIG_BACK                	GPIOPINDEF(0x0E,12, SCU_MODE_FUNC4, 7, 12)
#define DIST_CAP_BACK                 	GIMAPINDEF(0x02,13,(SCU_MODE_FUNC1 | SCU_MODE_INBUFF_EN | SCU_MODE_PULLDOWN), (0 << 4))
#else
#ifdef AM2
#define DIST_TRIG_FRONT                 GPIOPINDEF(0x0E, 13, SCU_MODE_FUNC4, 7, 13) // PATCH required!!
#define DIST_CAP_FRONT                  GIMAPINDEF(0x05, 3, (SCU_MODE_FUNC5 | SCU_MODE_INBUFF_EN | SCU_MODE_PULLDOWN), (1 << 4)) // patch required!    // T8 (timer 1 capture input 3, GIMA select T1_CAP3)
#define DIST_CAP_TIMER_INPUT_FRONT      3
#define DIST_TRIG_BACK                  GPIOPINDEF(0x05, 2, SCU_MODE_FUNC0, 2, 11) //ball R4
#define DIST_CAP_BACK                   GIMAPINDEF(0x02, 13, (SCU_MODE_FUNC1 | SCU_MODE_INBUFF_EN | SCU_MODE_PULLDOWN), (0 << 4))      // C16 (Timer 1 capture input 2, GIMA select CTIN_4)
#else
#error "Unrecognised board version"
#endif
#endif
#define DIST_CAP_TIMER_INPUT_BACK       (2)
#define DIST_INTPRIORITY                (7)
#define DIST_SAMPLE_RATE                20                                // 20 Hz
#define DIST_TIMER                      LPC_TIMER1                      /* Timer used for distance measurement*/
#define DIST_TIMER_INTERRUPT            TIMER1_IRQHandler               /* Ensure this matches with the line below!! */
#define DIST_TIMER_IRQ                  TIMER1_IRQn                     /* Ensure this matches with the line below!! */
#else
// ----- VL Distance Sensor (vldist.c)
// -----------------------------------

enum VLDIST_CHANNEL_ENUM {VLDIST_FRONT, VLDIST_REAR, VLDISTNONE };

#define NUM_VLS                         (VLDISTNONE)

#define VLS0ID                          0x10
#define VLS0EN                          GPIOPINDEF(0x01, 16, SCU_MODE_FUNC0, 0, 3)
#define VLS1ID                          0x11
#define VLS1EN                          GPIOPINDEF(0x07, 1, SCU_MODE_FUNC0, 3, 9)

#define VLSLIST                         {VLS0ID,VLS0EN},{VLS1ID,VLS1EN}

#endif
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

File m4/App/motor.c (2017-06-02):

/*
*                                       ++++++++++++++++++
*                                  +++++++++++++++++++++++++++++
*                              +++++++                      +++++++++
*                          +++++++                               +++++++++++++
*         ++++++++++++++++++++                                         ++++++++++
*    +++++++++++++++++++++                                                     +++
*   +++++                                                                       +++
*  +++         ######### ######### ########  #########  #########   +++++++      ++
*  +++  +++++ ####  #### ######## ####  #### ##### #### #### ####  +++  ++++    +++
*  +++   ++++ ###     ## ###      ###    ### ###    ### ###    ### ++++++++   +++
*   ++++ ++++ ########## ###      ########## ###    ### ###    ### ++++    +++++
*    +++++++   ###### ## ###       ########  ###     ## ##     ###  ++++++++++
*
* Copyright 2017 Technolution BV  opensource@technolution.eu
*
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
* Motor Control module
* ====================
*
* This module controls the motor system.
*
*/

#include <stdlib.h>
#include "motor.h"
#include "config.h"
#include "lms.h"
#include "ui.h"

static struct

{
    uint32_t stopDir;
    int32_t  speed;
    int32_t  period;
    uint32_t ticksPerMs;
    uint32_t servoAngle;
} _m;

enum motorDir {_MOTOR_OFF, _MOTOR_FORWARDS, _MOTOR_BACKWARDS};

/* Various PWM channels in use */
#define MOTOR_PWM_OUT        (1)
#define SERVO_PWM_OUT        (2)

/* ...and the rate for the PWM */
#define SCT_PWM_RATE         (50)        /* PWM frequency 50Hz (20mS) */

// ============================================================================================
void _runMotor( enum motorDir d )

{
    switch ( d )
    {
        case _MOTOR_OFF:
            Chip_GPIO_SetPinOutLow( LPC_GPIO_PORT, GETGPIOPORT( MOTOR0_M0 ), GETGPIOPIN( MOTOR0_M0 ) );
            Chip_GPIO_SetPinOutLow( LPC_GPIO_PORT, GETGPIOPORT( MOTOR0_M1 ), GETGPIOPIN( MOTOR0_M1 ) );
            break;

        case _MOTOR_BACKWARDS:
            Chip_GPIO_SetPinOutHigh( LPC_GPIO_PORT, GETGPIOPORT( MOTOR0_M0 ), GETGPIOPIN( MOTOR0_M0 ) );
            Chip_GPIO_SetPinOutLow( LPC_GPIO_PORT, GETGPIOPORT( MOTOR0_M1 ), GETGPIOPIN( MOTOR0_M1 ) );
            break;

        case _MOTOR_FORWARDS:
            Chip_GPIO_SetPinOutLow( LPC_GPIO_PORT, GETGPIOPORT( MOTOR0_M0 ), GETGPIOPIN( MOTOR0_M0 ) );
            Chip_GPIO_SetPinOutHigh( LPC_GPIO_PORT, GETGPIOPORT( MOTOR0_M1 ), GETGPIOPIN( MOTOR0_M1 ) );
            break;
    }

    Chip_SCTPWM_SetDutyCycle( LPC_SCT, MOTOR_PWM_OUT, Chip_SCTPWM_PercentageToTicks( LPC_SCT, abs( _m.speed ) ) );
}
// ============================================================================================
// ============================================================================================
// ============================================================================================
// Publicly available routines
// ============================================================================================
// ============================================================================================
// ============================================================================================
BOOL motorSpeed( int32_t speed )

{
    if ( abs( speed ) > 100 )
    {
        return FALSE;
    }

    _m.speed = speed;

    if  ( ( _m.speed == 0 ) ||
            ( ( _m.speed > 0 ) && ( _m.stopDir & MOTOR_ESTOP_FORWARDS ) ) ||
            ( ( _m.speed < 0 ) && ( _m.stopDir & MOTOR_ESTOP_BACKWARDS ) ) )
    {
        _runMotor( _MOTOR_OFF );
    }
    else if ( _m.speed > 0 )
    {
        _runMotor( _MOTOR_FORWARDS );
    }
    else if ( _m.speed < 0 )
    {
        _runMotor( _MOTOR_BACKWARDS );
    }

    return TRUE;
}
// ============================================================================================
BOOL motorSeteStop( uint32_t stopDirSet )

{
    _m.stopDir |= stopDirSet;

    /* motorSpeed performs eStop checking */
    return motorSpeed( _m.speed );
}
// ============================================================================================
BOOL motorCleareStop( uint32_t unstopDirSet )

{
    _m.stopDir &= ~unstopDirSet;

    /* motorSpeed performs eStop checking */
    return motorSpeed( _m.speed );
}
// ============================================================================================
BOOL motorGeteStop( uint32_t direction )

{
    return ( _m.stopDir & direction ) != 0;
}
// ============================================================================================
int32_t motorGetSpeed( void )

{
    return _m.speed;
}
// ============================================================================================
BOOL motorServoSet( uint32_t level )

/* Set servo PWM level */

{
    /* level value between 0 and 1000 results in a pulse width between  1us and 2us */
    Chip_SCTPWM_SetDutyCycle( LPC_SCT, SERVO_PWM_OUT, _m.ticksPerMs + ( ( _m.ticksPerMs * level ) / PWM_SERVO_RANGE ) );
    _m.servoAngle = level;
    return TRUE;
}
// ============================================================================================
uint32_t motorServoGet( void )

/* Get servo PWM level */

{
    return _m.servoAngle;
}
// ============================================================================================
void motorServoReset( void )

{
    motorServoSet( PWM_SERVO_RANGE / 2 );
}
// ============================================================================================
void motorInit( void )
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

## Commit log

2017-04-28 Initial commit from llb_v2
    [crossbar.scad, doxygen.cfg, top-v4.dwg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]
2017-05-04 Addition of wiring diagrams
2017-05-05 PNG Version of power wiring
2017-05-05 Wiring updates
2017-05-24 Addition of 3D print files for crossbars front and rear
    [bakcrossbar.stl, crossbar.scad, frontcrossbar.stl]
2017-05-26 Changes to build on Linux in addition to OSX, plus addition of LED critical section
2017-05-28 Improvements to LED handling
2017-06-01 Watchdog rebooting of M0 in case of failure of that CPU
    [mainloop_m4.c]
2017-06-02 Pretty printing and general code tidy
